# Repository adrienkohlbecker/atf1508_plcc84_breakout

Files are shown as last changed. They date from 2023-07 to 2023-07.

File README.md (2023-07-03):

# ATF1508 Breakout

Breakout board for Atmel's AFT1508 CPLDs in a through-hole PLCC-84 socket. The size is friendly for breadboard use, with two rows of holes left available on each side of the breadboard for wires to come in.

## Board

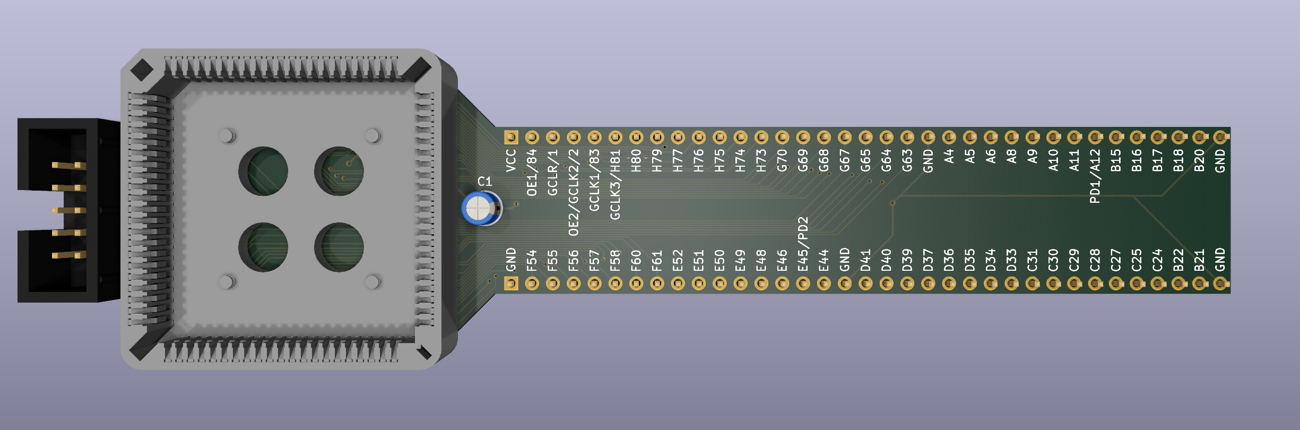
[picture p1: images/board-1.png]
board-1


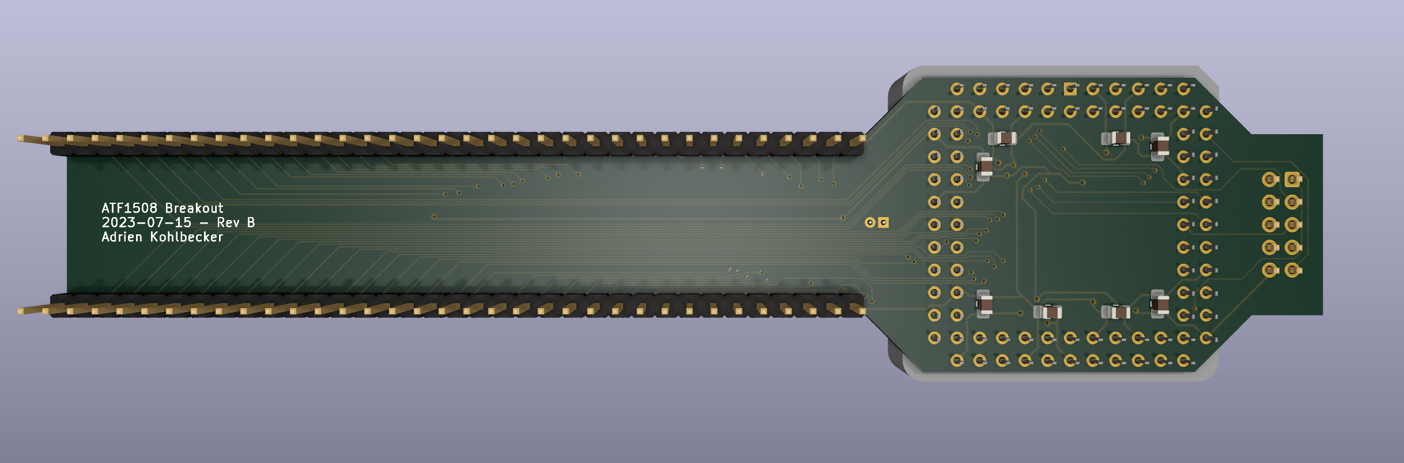
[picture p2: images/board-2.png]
board-2


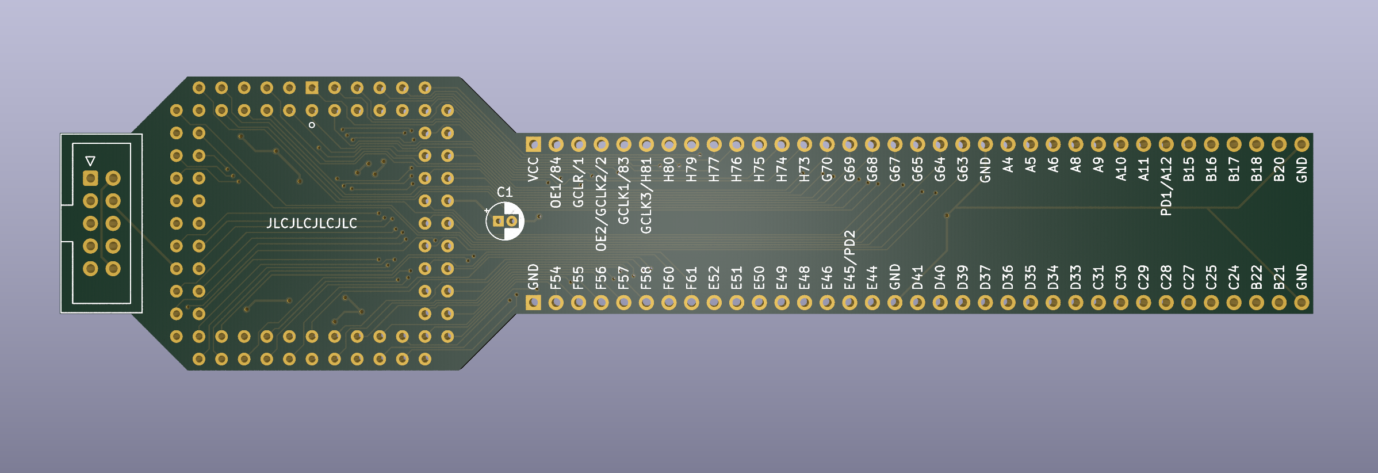
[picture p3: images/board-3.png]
board-3


## Schematic

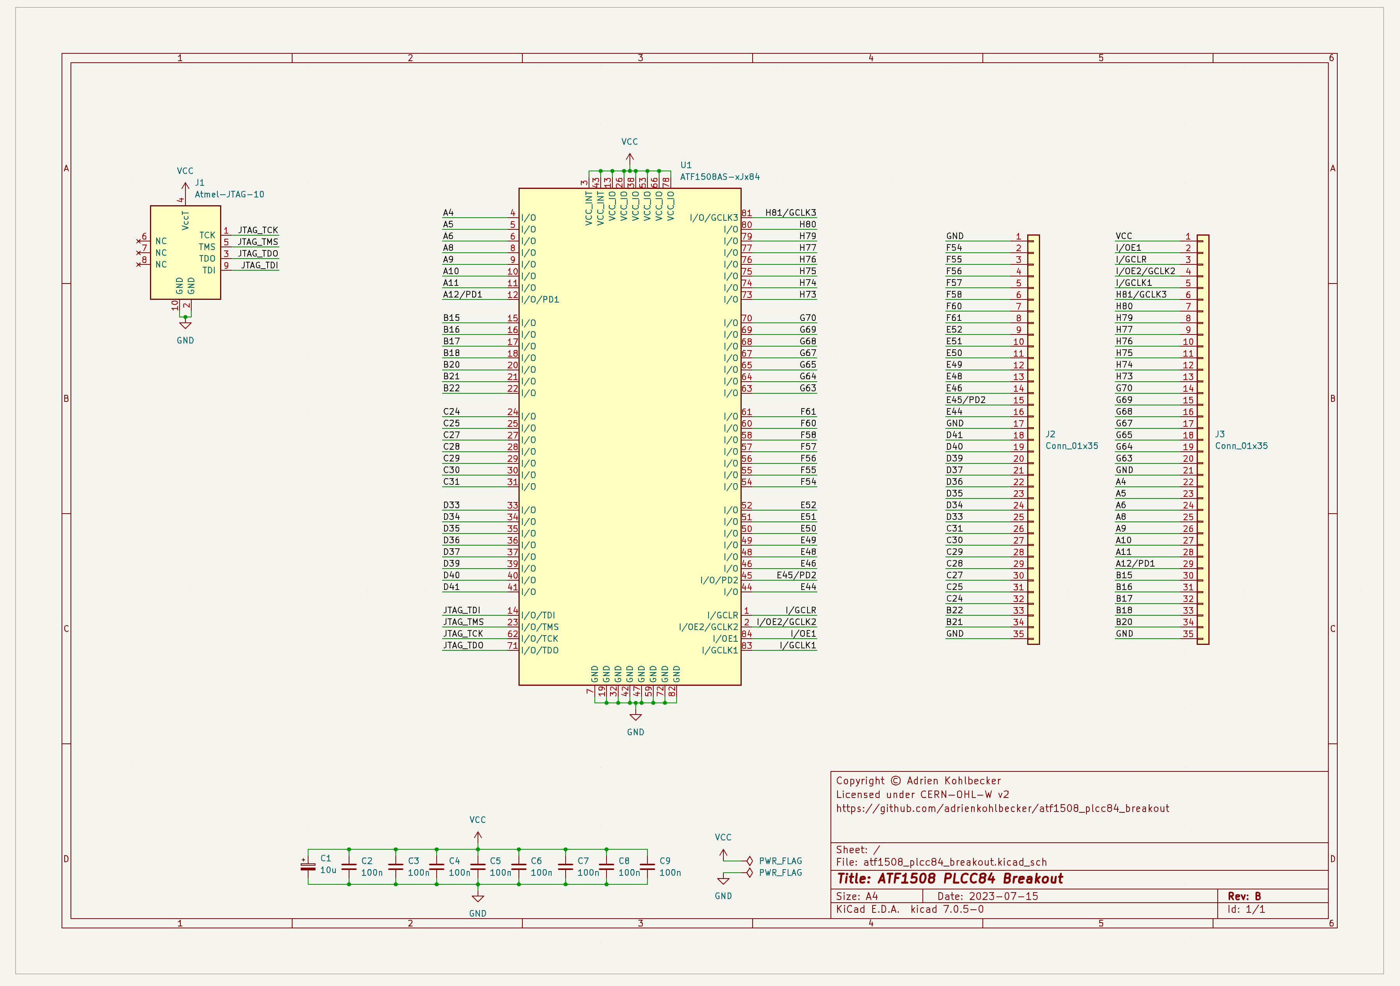
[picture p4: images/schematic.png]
schematic


## BOM

| Refs | Qty | Component | Description |
| ----- | --- | ---- | --- |
| C1 | 1 | 10u | Polarized capacitor, through hole D4.0mm P1.5mm |
| C2, C3, C4, C5, C6, C7, C8, C9 | 8 | 100n | Unpolarized capacitor, 0805 SMD |
| J1 | 1 | Atmel-JTAG-10 | Atmel 10-pin JTAG connector, 2x5 IDC |
| J2, J3 | 2 | Conn_01x35 | Generic connector, single row, 01x35 |
| U1 | 1 | ATF1508AS-xJx84 | Microchip CPLD, in PLCC-84 through-hole socket |

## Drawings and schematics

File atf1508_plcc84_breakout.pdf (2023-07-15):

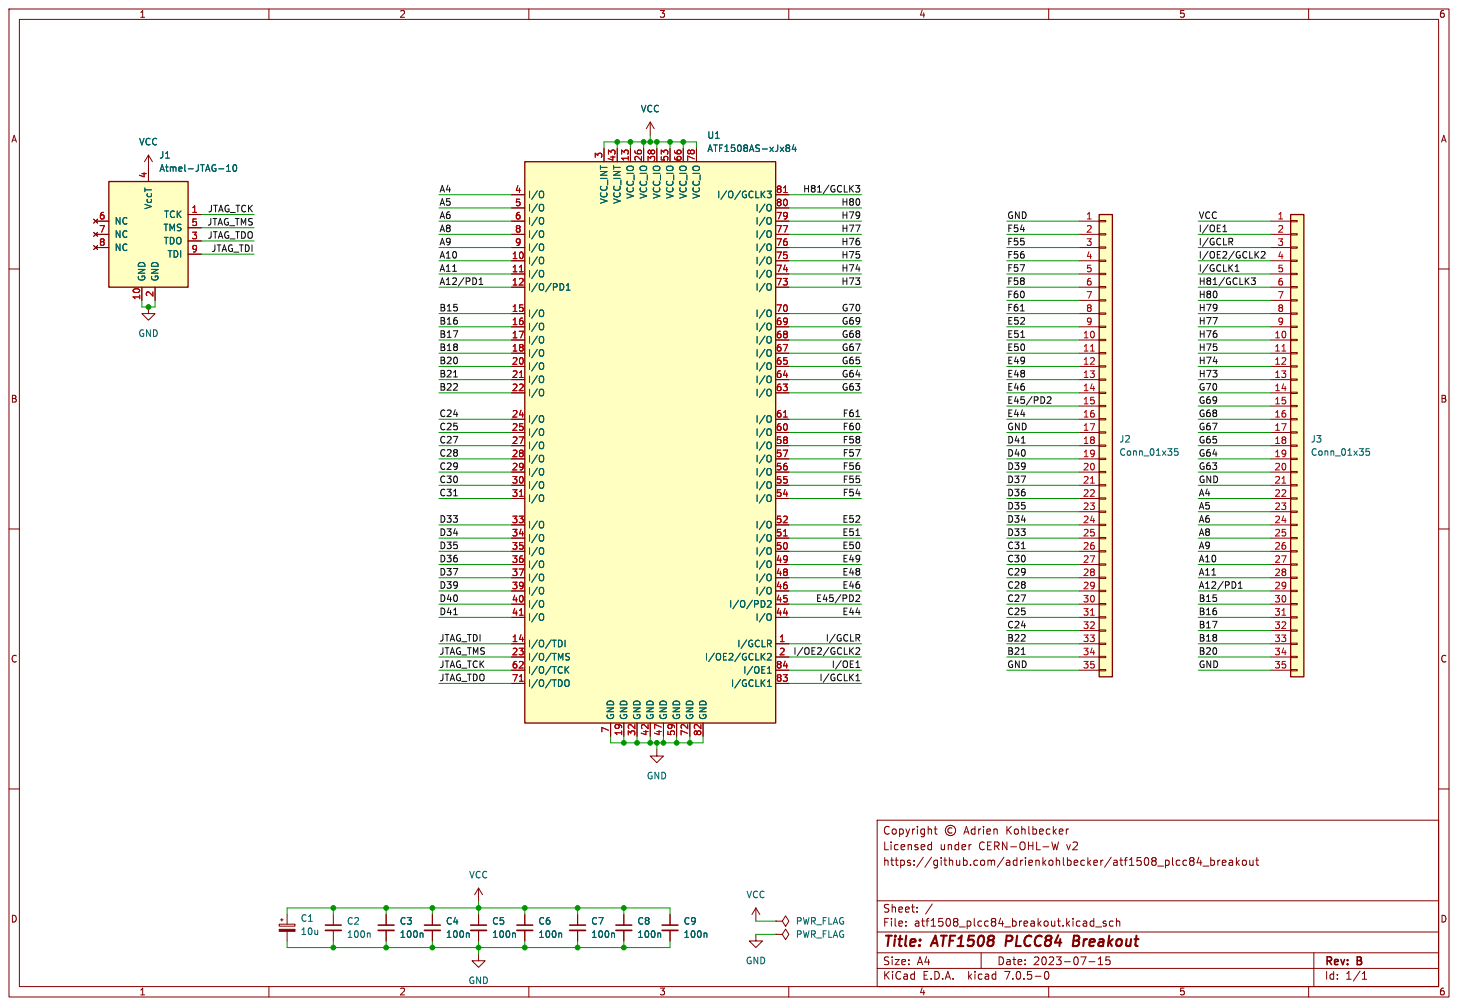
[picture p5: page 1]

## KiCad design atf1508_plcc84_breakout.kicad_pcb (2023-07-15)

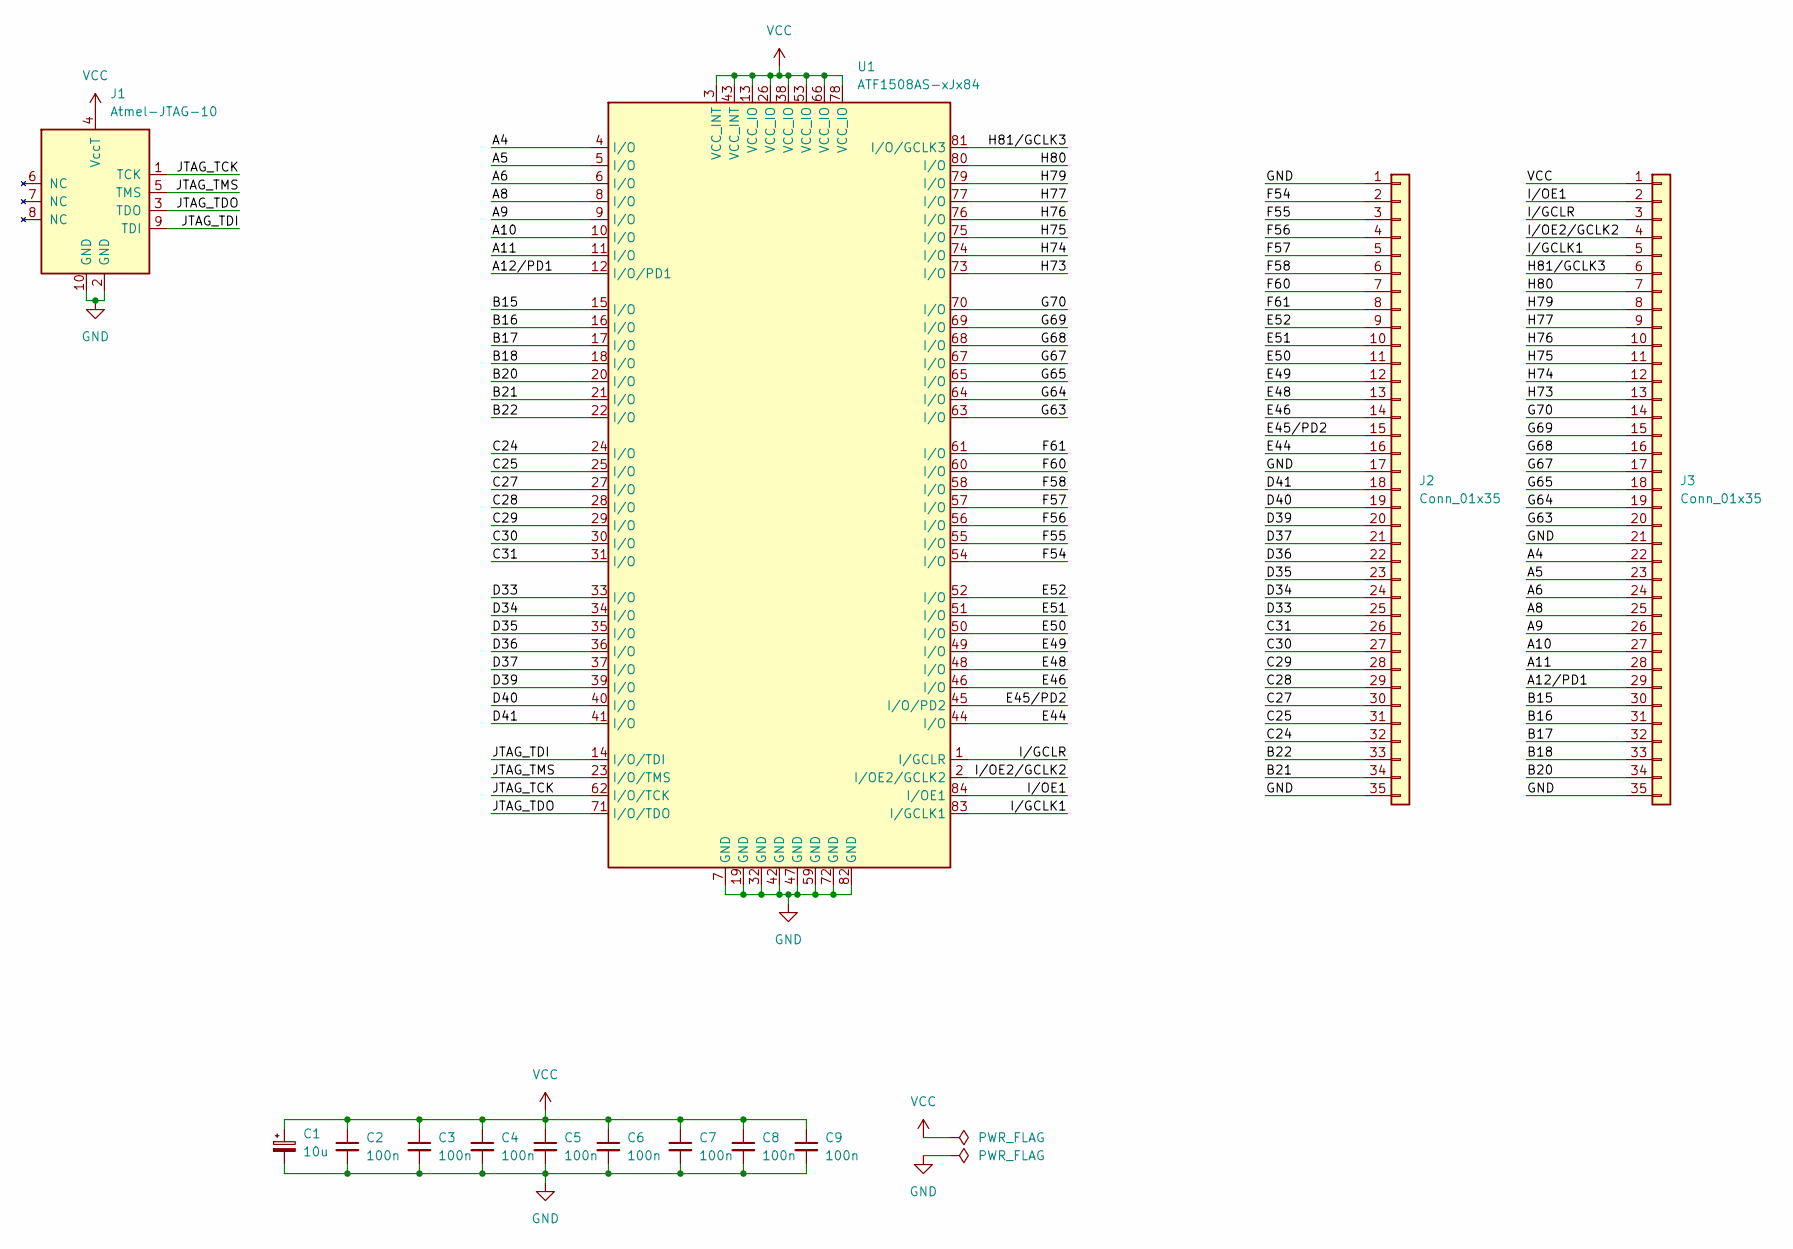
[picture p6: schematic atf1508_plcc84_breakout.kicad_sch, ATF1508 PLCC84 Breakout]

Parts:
C1: 10u; CP_Radial_D4.0mm_P1.50mm
C2, C3, C4, C5, C6, C7, C8, C9: 100n; C_0805_2012Metric_Pad1.18x1.45mm_HandSolder
J1: Atmel-JTAG-10; IDC-Header_2x05_P2.54mm_Vertical
J2, J3: Conn_01x35; PinHeader_1x35_P2.54mm_Vertical
U1: ATF1508AS-xJx84; PLCC-84_THT-Socket

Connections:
/A4: J3.22, U1.4 (I/O)
/A5: J3.23, U1.5 (I/O)
/A6: J3.24, U1.6 (I/O)
/A8: J3.25, U1.8 (I/O)
/A9: J3.26, U1.9 (I/O)
/A10: J3.27, U1.10 (I/O)
/A11: J3.28, U1.11 (I/O)
/A12/PD1: J3.29, U1.12 (I/O/PD1)
/B15: J3.30, U1.15 (I/O)
/B16: J3.31, U1.16 (I/O)
/B17: J3.32, U1.17 (I/O)
/B18: J3.33, U1.18 (I/O)
/B20: J3.34, U1.20 (I/O)
/B21: J2.34, U1.21 (I/O)
/B22: J2.33, U1.22 (I/O)
/C24: J2.32, U1.24 (I/O)
/C25: J2.31, U1.25 (I/O)
/C27: J2.30, U1.27 (I/O)
/C28: J2.29, U1.28 (I/O)
/C29: J2.28, U1.29 (I/O)
/C30: J2.27, U1.30 (I/O)
/C31: J2.26, U1.31 (I/O)
/D33: J2.25, U1.33 (I/O)
/D34: J2.24, U1.34 (I/O)
/D35: J2.23, U1.35 (I/O)
/D36: J2.22, U1.36 (I/O)
/D37: J2.21, U1.37 (I/O)
/D39: J2.20, U1.39 (I/O)
/D40: J2.19, U1.40 (I/O)
/D41: J2.18, U1.41 (I/O)
/E44: J2.16, U1.44 (I/O)
/E45/PD2: J2.15, U1.45 (I/O/PD2)
/E46: J2.14, U1.46 (I/O)
/E48: J2.13, U1.48 (I/O)
/E49: J2.12, U1.49 (I/O)
/E50: J2.11, U1.50 (I/O)
/E51: J2.10, U1.51 (I/O)
/E52: J2.9, U1.52 (I/O)
/F54: J2.2, U1.54 (I/O)
/F55: J2.3, U1.55 (I/O)
/F56: J2.4, U1.56 (I/O)
/F57: J2.5, U1.57 (I/O)
/F58: J2.6, U1.58 (I/O)
/F60: J2.7, U1.60 (I/O)
/F61: J2.8, U1.61 (I/O)
/G63: J3.20, U1.63 (I/O)
/G64: J3.19, U1.64 (I/O)
/G65: J3.18, U1.65 (I/O)
/G67: J3.17, U1.67 (I/O)
/G68: J3.16, U1.68 (I/O)
/G69: J3.15, U1.69 (I/O)
/G70: J3.14, U1.70 (I/O)
/H73: J3.13, U1.73 (I/O)
/H74: J3.12, U1.74 (I/O)
/H75: J3.11, U1.75 (I/O)
/H76: J3.10, U1.76 (I/O)
/H77: J3.9, U1.77 (I/O)
/H79: J3.8, U1.79 (I/O)
/H80: J3.7, U1.80 (I/O)
/H81/GCLK3: J3.6, U1.81 (I/O/GCLK3)
/I/GCLK1: J3.5, U1.83 (I/GCLK1)
/I/GCLR: J3.3, U1.1 (I/GCLR)
/I/OE1: J3.2, U1.84 (I/OE1)
/I/OE2/GCLK2: J3.4, U1.2 (I/OE2/GCLK2)
/JTAG_TCK: J1.1 (TCK), U1.62 (I/O/TCK)
/JTAG_TDI: J1.9 (TDI), U1.14 (I/O/TDI)
/JTAG_TDO: J1.3 (TDO), U1.71 (I/O/TDO)
/JTAG_TMS: J1.5 (TMS), U1.23 (I/O/TMS)
GND: C1.2, C2.2, C3.2, C4.2, C5.2, C6.2, C7.2, C8.2, C9.2, J1.2 (GND), J1.10 (GND), J2.1, J2.17, J2.35, J3.21, J3.35, U1.7 (GND), U1.19 (GND), U1.32 (GND), U1.42 (GND), U1.47 (GND), U1.59 (GND), U1.72 (GND), U1.82 (GND); also elsewhere on the board
VCC: C1.1, C2.1, C3.1, C4.1, C5.1, C6.1, C7.1, C8.1, C9.1, J1.4 (VccT), J3.1, U1.3 (VCC_INT), U1.13 (VCC_IO), U1.26 (VCC_IO), U1.38 (VCC_IO), U1.43 (VCC_INT), U1.53 (VCC_IO), U1.66 (VCC_IO), U1.78 (VCC_IO); also elsewhere on the board

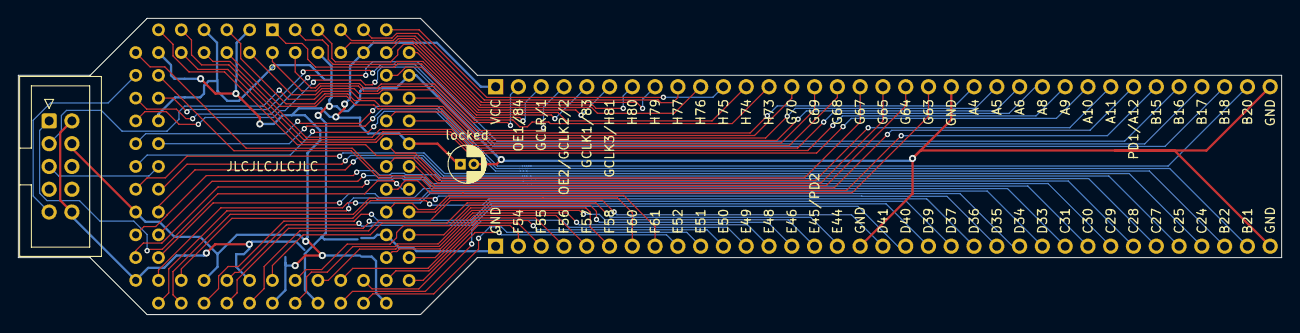
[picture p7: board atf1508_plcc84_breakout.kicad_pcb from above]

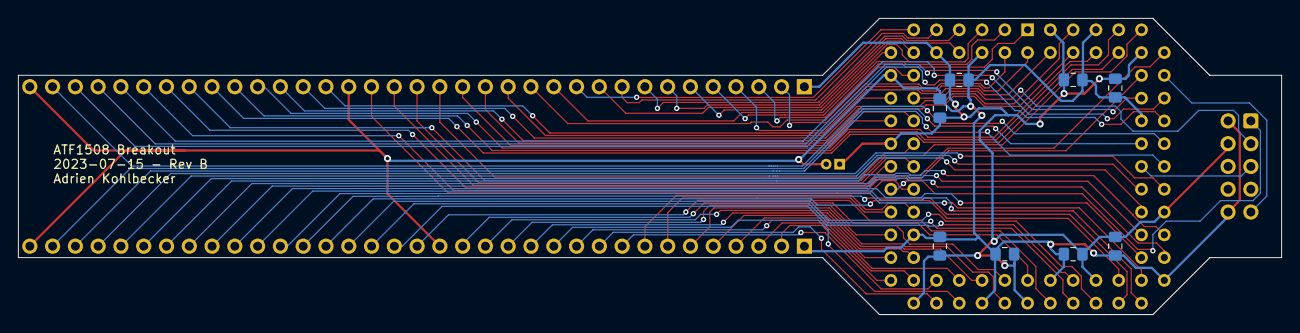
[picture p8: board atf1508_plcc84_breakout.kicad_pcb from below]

Board: 2 copper layers, 140.8 x 33.0 mm, 13 parts (10 on the bottom side), 70 nets.

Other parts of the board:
locked: 10u; CP_Radial_D4.0mm_P1.50mm

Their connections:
GND: locked.2; also elsewhere on the board
VCC: locked.1; also elsewhere on the board

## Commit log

2023-06-20 First release
    [atf1508_plcc84_breakout-B_Cu.gbl, atf1508_plcc84_breakout-B_Mask.gbs, atf1508_plcc84_breakout-B_Paste.gbp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]
2023-07-03 Revert oscillator addition
    [atf1508_plcc84_breakout-B_Cu.gbl, atf1508_plcc84_breakout-B_Mask.gbs, atf1508_plcc84_breakout-B_Paste.gbp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]
2023-07-15 Add pin numbers for global inputs and re-order them
    [atf1508_plcc84_breakout-B_Cu.gbl, atf1508_plcc84_breakout-B_Mask.gbs, atf1508_plcc84_breakout-B_Paste.gbp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]

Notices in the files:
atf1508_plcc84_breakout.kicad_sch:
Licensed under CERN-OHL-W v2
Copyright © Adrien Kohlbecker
